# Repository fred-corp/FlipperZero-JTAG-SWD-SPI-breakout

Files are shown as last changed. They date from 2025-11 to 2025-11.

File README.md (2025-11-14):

# Flipper Zero JTAG/SWD/SPI breakout

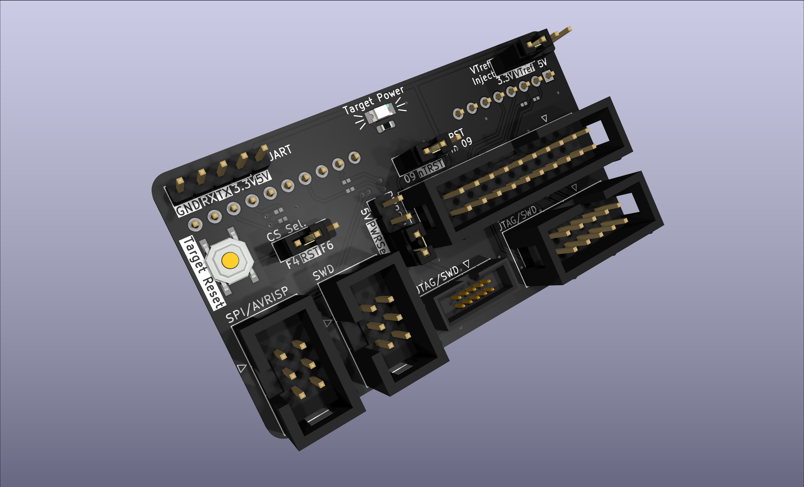
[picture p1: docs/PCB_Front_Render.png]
Flipper Zero JTAG/SWD/SPI breakout board front

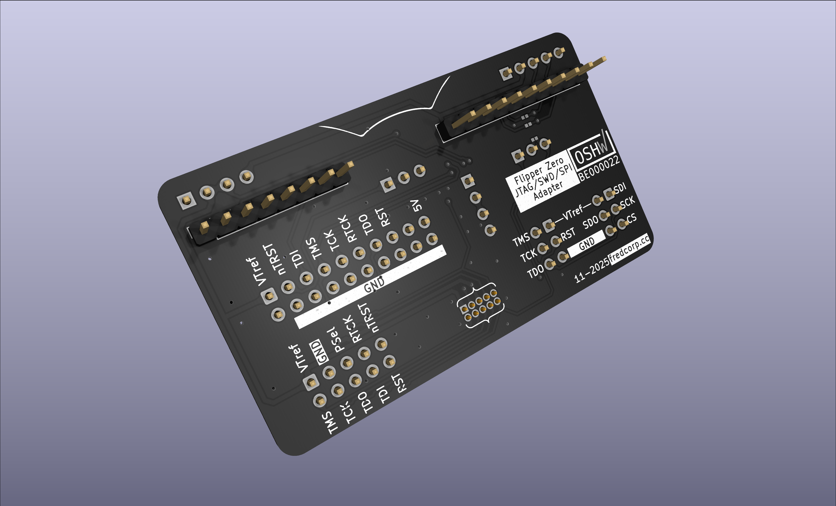
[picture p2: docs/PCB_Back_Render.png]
Flipper Zero JTAG/SWD/SPI breakout board back


A simple breakout board to connect a Flipper Zero to JTAG/SWD/SPI targets.

OSHW ID : [BE000022](https://certification.oshwa.org/be000022.html)

## Table of Contents

- [Features](#features)
  - [Compatible Apps](#compatible-apps)
  - [Pin selection](#pin-selection)
- [Pinouts](#pinouts)
  - [Flipper Zero GPIO header](#flipper-zero-gpio-header)
  - [20 pin JTAG 2x10 0.1" header](#20-pin-jtag-2x10-01-header)
  - [10 pin JTAG/SWD 2x5 0.1" and 0.05" header](#10-pin-jtagswd-2x5-01-and-005-header)
  - [6 pin SWD 2x3 0.1" header](#6-pin-swd-2x3-01-header)
  - [6 pin SPI 2x3 0.1" header](#6-pin-spi-2x3-01-header)
  - [5 pin UART 1x5 0.1" header](#5-pin-uart-1x5-01-header)
- [Usage](#usage)
- [Building Instructions](#building-instructions)
- [Sources](#sources)
- [License & Acknowledgements](#license--acknowledgements)

## Features

Convert the Flipper Zero's GPIO port into standard headers for JTAG, SWD, SPI, and UART connections.

### Compatible Apps

The board should be compatible with any apps that use the Flipper Zero's GPIO port for JTAG/SWD/SPI communication, though the following where the main targets during development for the pin selection and configuration :

- [DAP Link](https://lab.flipper.net/apps/dap_link) (JTAG/SWD & UART)
- [SWD Probe](https://lab.flipper.net/apps/swd_probe) (SWD)
- [SPI Mem Manager](https://lab.flipper.net/apps/spi_mem_manager) (SPI)
- [SPI-Terminal](https://lab.flipper.net/apps/flipper_spi_terminal) (SPI)
- [UART Terminal](https://lab.flipper.net/apps/uart_terminal) (UART)
- [ESP Flasher](https://lab.flipper.net/apps/esp_flasher) (UART)

> **Note** :  
Not all JTAG signals are used by the Flipper Zero apps, but the board can also be used to convert from a 20-pin ARM JTAG connector from another programmer to 10 or 6 pin headers.  
It can also be used as a SWD interface with the Flipper Zero as a target, by bridging the TCK and TMS signals to GPIO 10 and GPIO 12 via their corresponding solder jumpers. This enables programming/debugging the Flipper Zero itself with an external programmer.

### Pin selection

Depending on the app's requirements, some signals can be connected to different GPIO pins of the Flipper Zero using solder jumpers (see assembly instructions/schematics) :

- The TCK signal can be connected to GPIO 2 or GPIO 10
- The TMS signal can be connected to GPIO 3 or GPIO 12
- The UART TX pin can be connected to GPIO 13 or GPIO 15
- The UART RX pin can be connected to GPIO 14 or GPIO 16
- The SPI CS pin can be connected to GPIO 4

Other pins can be configured with jumper shunts :

- The VTref signal can be connected to 3.3V, 5V, or left floating
- The PWRSel signal can be connected to 5V or GND depending on the target's pinout
- The nTRST signal on the 10 pin headers can be connected to nTRST or left floating (NC)
- The SPI CS signal on the 6 pin SPI header can be connected to GPIO 4 or GPIO 6

## Pinouts

> Note : *Italic* pins are configurable with the solder jumpers

### Flipper Zero GPIO header

| Pin | Signals |
|-----|---|
| 1 | 5V |
| 2 | SPI-SDO, *JTAG-TCK* |
| 3 | SPI-SDI, *JTAG-TMS* |
| 4 | *SPI-CS*, JTAG-nRESET |
| 5 | SPI-SCK, JTAG-TDO |
| 6 | *SPI-CS*, JTAG-TDI |
| 7 | NC |
| 8 | GND |
| | |
| 9 | 3.3V |
| 10  | *JTAG-TCK* |
| 11  | GND |
| 12  | *JTAG-TMS* |
| 13  | *UART_TX* |
| 14  | *UART-RX* |
| 15  | *UART-TX* |
| 16  | *UART-RX* |
| 17  | NC |
| 18  | GND |

### 20 pin JTAG 2x10 0.1" header

| Signal | Pin | Pin | Signal |
|---|-----|-----|---|
| VTref | 1 | 2 | NC |
| nTRST | 3 | 4 | GND |
| TDI | 5 | 6 | GND |
| TMS | 7 | 8 | GND |
| TCK | 9 | 10  | GND |
| RTCK | 11  | 12  | GND |
| TDO | 13  | 14  | GND |
| nRESET | 15  | 16  | GND |
| NC | 17  | 18  | GND |
| 5V-Supply | 19  | 20  | GND |

### 10 pin JTAG/SWD 2x5 0.1" and 0.05" header

| Signal | Pin | Pin | Signal |
|---|-----|-----|---|
| VTref | 1 | 2 | TMS |
| GND | 3 | 4 | TCK |
| *PWRSel* | 5 | 6 | TDO |
| RTCK | 7 | 8 | TDI |
| *nTRST/NC* | 9 | 10  | nRESET |

### 6 pin SWD 2x3 0.1" header

| Signal | Pin | Pin | Signal |
|---|-----|-----|---|
| VTref  | 1 | 2 | TMS |
| nRESET | 3 | 4 | TCK |
| GND | 5 | 6 | TDO |

### 6 pin SPI 2x3 0.1" header

| Signal | Pin | Pin | Signal  |
|---|-----|-----|---|
| SDI | 1 | 2 | VTref |
| SCK | 3 | 4 | SDO |
| *CS* | 5 | 6 | GND |

The CS pin can be connected to GPIO 4 or GPIO 6 of the Flipper Zero, depending on the app's requirements.

### 5 pin UART 1x5 0.1" header

| Pin | Signal |
|-----|---|
| 1 | 5V |
| 2 | 3.3V |
| 3 | TX |
| 4 | RX |
| 5 | GND |

## Usage

> TODO : Add usage instructions for some Flipper Zero apps (e.G. DAP Link, SPI mem manager, etc.)

## Building Instructions

> TODO : Add assembly instructions and wiring diagrams from KiCAD sources (awaiting OSHWA certification).

## Sources

- [Flipper Zero Documentation](https://docs.flipperzero.one/)
- [Segger JTAG pinouts](https://www.segger.com/products/debug-probes/j-link/technology/interface-description/)
- [ARM JTAG/SWD pinouts](https://developer.arm.com/documentation/dui0499/d/ARM-DSTREAM-Target-Interface-Connections/)
- [AVR ISP pinouts](https://www.microchip.com/en-us/development-tool/atavrisp2)

## License & Acknowledgements

Made with ❤️, lots of ☕️, and lack of 🛌  
Published under CreativeCommons BY-SA 4.0

  
This work is licensed under a [Creative Commons Attribution-ShareAlike 4.0 International License](http://creativecommons.org/licenses/by-sa/4.0/).

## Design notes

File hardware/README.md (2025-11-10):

# Hardware

This folder contains the KiCAD PCB Project files for the FlipperZero ARM JTAG breakout board.

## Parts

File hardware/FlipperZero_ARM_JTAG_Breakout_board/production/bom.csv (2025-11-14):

Designator | Footprint | Quantity | Value | LCSC Part #
A1a | Flipper_Zero_Straight_8pin | 1 | Flipper_Zero | C42431813
A1b | Flipper_Zero_Straight_10pin | 1 | Flipper_Zero | C42431810
J1 | IDC-Header_2x10_P2.54mm_Vertical | 1 | ARM-JTAG | C429961
J10 | PinHeader_1x03_P2.54mm_Vertical | 1 | nTRST_EN | C42431836
J2 | IDC-Header_2x05_P2.54mm_Vertical | 1 | TC2050-IDC | C429962
J3 | IDC-TH_10P-P1.27-V-M-R2-C5-S1.27 | 1 | 1.27mm | C50878437
J4 | IDC-Header_2x03_P2.54mm_Vertical | 1 | TC2030-IDC | C4749192
J5 | IDC-Header_2x03_P2.54mm_Vertical | 1 | SPI/ISP | C4749192
J6 | PinHeader_1x05_P2.54mm_Vertical | 1 | UART | C42431835
J7 | PinHeader_1x04_P2.54mm_Vertical | 1 | VTrefSel | C42431808
J8 | PinHeader_1x04_P2.54mm_Vertical | 1 | PWRSel | C42431808
J9 | PinHeader_1x03_P2.54mm_Vertical | 1 | RSTSel | C42431836
LED1 | LED1206-R-RD_ORANGE | 1 | XL-3216UOC | C965823
R1 | 0603 | 1 | 150 | C2907103
SW1 | SW-SMD_4P-L5.2-W5.2-P3.70-LS6.4 | 1 | TS1187A16015 | C22375382
 |  | 4 | 2.54mm_shunt | C100114

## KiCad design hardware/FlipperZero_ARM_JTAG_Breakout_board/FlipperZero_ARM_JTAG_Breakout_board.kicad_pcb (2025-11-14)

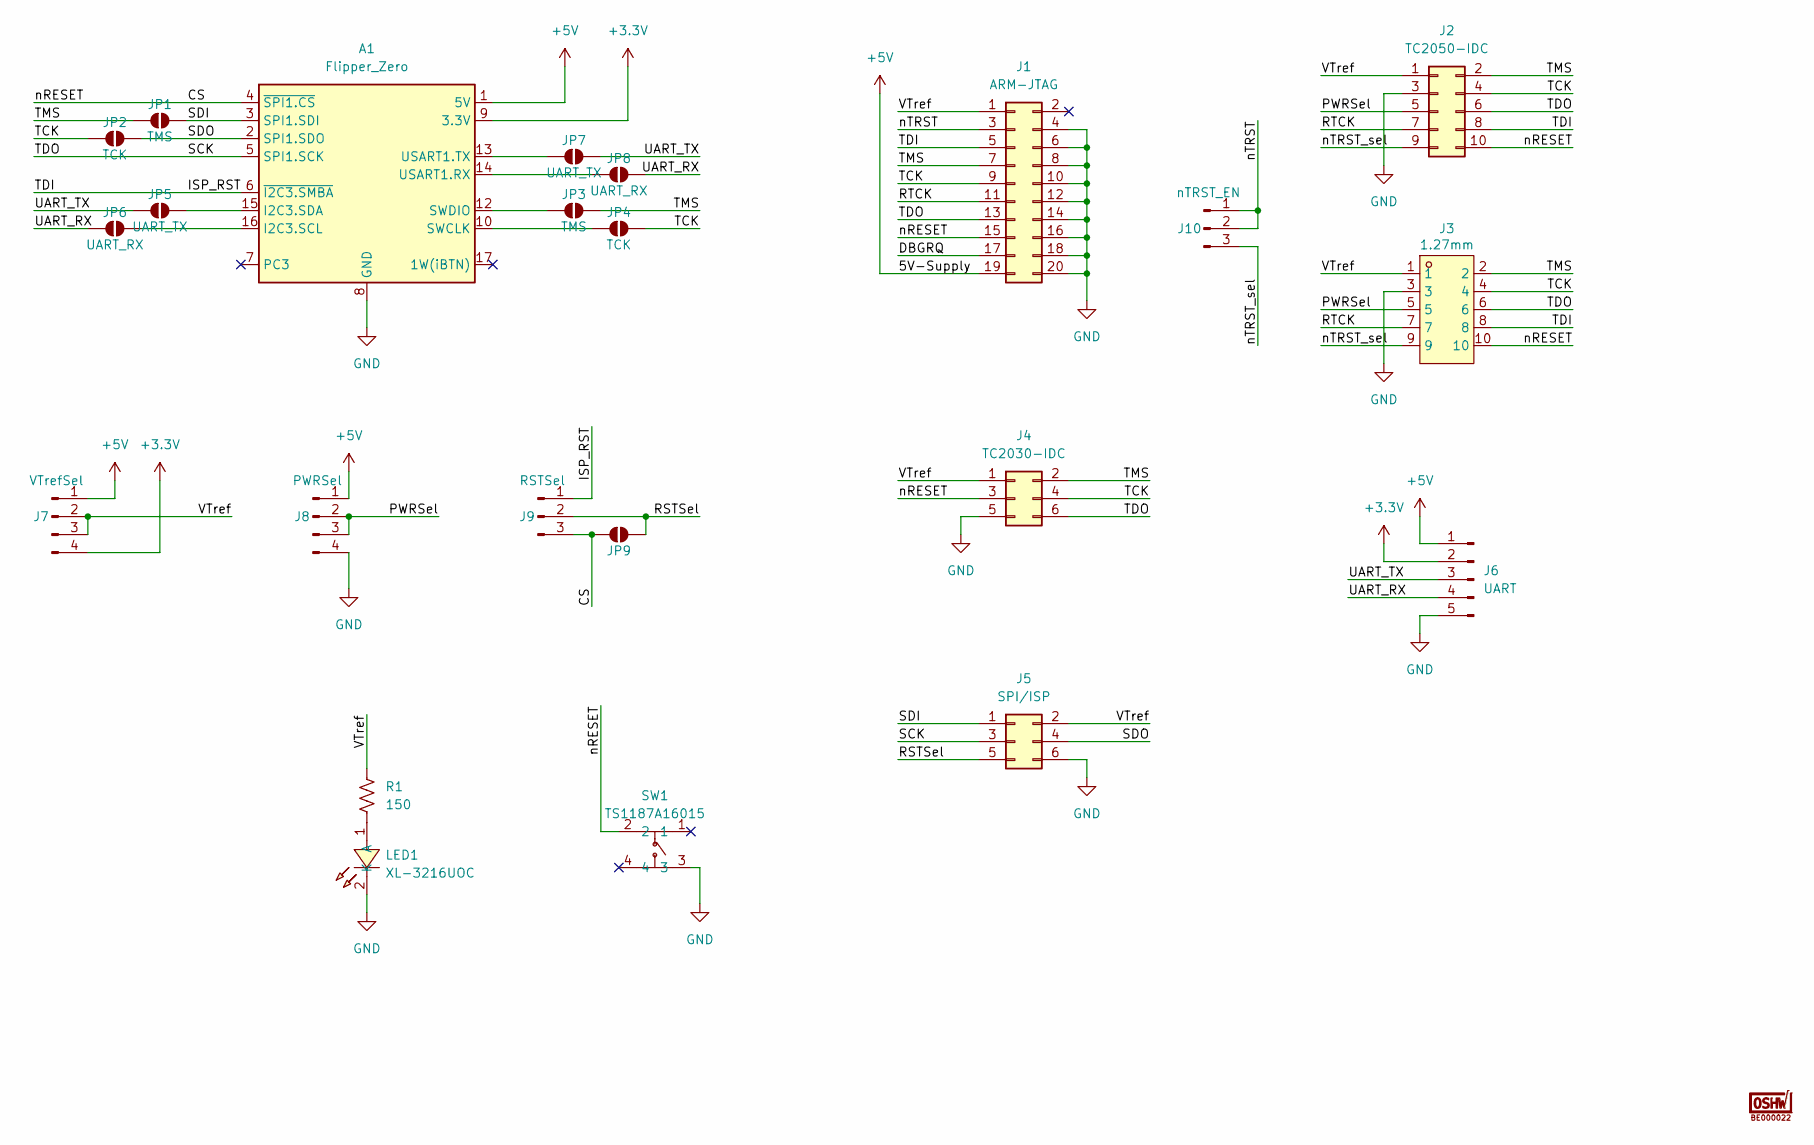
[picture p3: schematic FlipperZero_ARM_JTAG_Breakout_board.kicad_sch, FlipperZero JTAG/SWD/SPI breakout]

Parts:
A1: Flipper_Zero; Flipper_Zero_Straight
J1: ARM-JTAG; IDC-Header_2x10_P2.54mm_Vertical; LCSC Part C429961
J2: TC2050-IDC; IDC-Header_2x05_P2.54mm_Vertical; LCSC Part C429962
J3: 1.27mm; IDC-TH_10P-P1.27-V-M-R2-C5-S1.27; LCSC Part C50878437
J4: TC2030-IDC; IDC-Header_2x03_P2.54mm_Vertical; LCSC Part C4749192
J5: SPI/ISP; IDC-Header_2x03_P2.54mm_Vertical; LCSC Part C4749192
J6: UART; PinHeader_1x05_P2.54mm_Vertical
J7: VTrefSel; PinHeader_1x04_P2.54mm_Vertical
J8: PWRSel; PinHeader_1x04_P2.54mm_Vertical
J9: RSTSel; PinHeader_1x03_P2.54mm_Vertical
J10: nTRST_EN; PinHeader_1x03_P2.54mm_Vertical
JP1, JP3, JP9: TMS; JUMPER_SMD_1x2_tiny
JP2, JP4: TCK; JUMPER_SMD_1x2_tiny
JP5, JP7: UART_TX; JUMPER_SMD_1x2_tiny
JP6, JP8: UART_RX; JUMPER_SMD_1x2_tiny
LED1: XL-3216UOC; LED1206-R-RD_ORANGE; LCSC Part C965823
LOGO1: BE000022; OSHW-Certification-Mark-Stacked_8x7mm_SilkMask
R1: 150; R_0603_1608Metric_Pad0.98x0.95mm_HandSolder; LCSC Part C2907103
SW1: TS1187A16015; SW-SMD_4P-L5.2-W5.2-P3.70-LS6.4; LCSC Part C22375382

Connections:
+3.3V: A1.9 (3.3V), J6.2, J7.4
+5V: A1.1 (5V), J1.19, J6.1, J7.1, J8.1
/CS: A1.4 (~SPI1.CS), J1.15, J2.10, J3.10, J4.3, J9.3, JP9.1 (A), SW1.2
/DBGRQ: J1.17
/ISP_RST: A1.6 (~I2C3.SMBA), J1.5, J2.8, J3.8, J9.1
/PWRSel: J2.5, J3.5, J8.2, J8.3
/RSTSel: J5.5, J9.2, JP9.2 (B)
/RTCK: J1.11, J2.7, J3.7
/SCK: A1.5 (SPI1.SCK), J1.13, J2.6, J3.6, J4.6, J5.3
/SDI: A1.3 (SPI1.SDI), J5.1, JP1.1 (A)
/SDO: A1.2 (SPI1.SDO), J5.4, JP2.1 (A)
/TCK: J1.9, J2.4, J3.4, J4.4, JP2.2 (B), JP4.2 (B)
/TMS: J1.7, J2.2, J3.2, J4.2, JP1.2 (B), JP3.2 (B)
/UART_RX: J6.4, JP6.2 (B), JP8.2 (B)
/UART_TX: J6.3, JP5.2 (B), JP7.2 (B)
/VTref: J1.1, J2.1, J3.1, J4.1, J5.2, J7.2, J7.3, R1.1
/nTRST: J1.3, J10.1, J10.2
/nTRST_sel: J2.9, J3.9, J10.3
GND: A1.8 (GND), A1.11 (GND), A1.18 (GND), J1.4, J1.6, J1.8, J1.10, J1.12, J1.14, J1.16, J1.18, J1.20, J2.3, J3.3, J4.5, J5.6, J6.5, J8.4, LED1.2 (K), SW1.3
unnamed: A1.16 (I2C3.SCL), JP6.1 (A)
unnamed: A1.15 (I2C3.SDA), JP5.1 (A)
unnamed: A1.10 (SWCLK), JP4.1 (A)
unnamed: A1.12 (SWDIO), JP3.1 (A)
unnamed: A1.14 (USART1.RX), JP8.1 (A)
unnamed: A1.13 (USART1.TX), JP7.1 (A)
unnamed: LED1.1 (A), R1.2

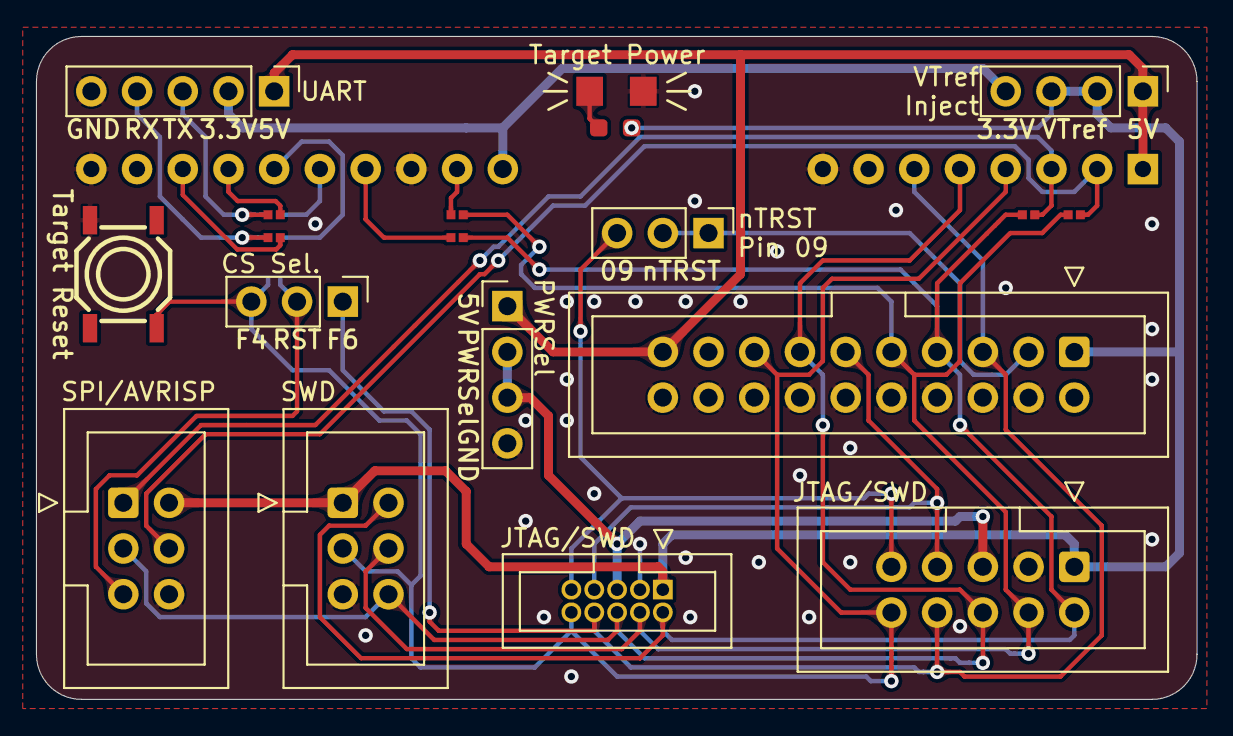
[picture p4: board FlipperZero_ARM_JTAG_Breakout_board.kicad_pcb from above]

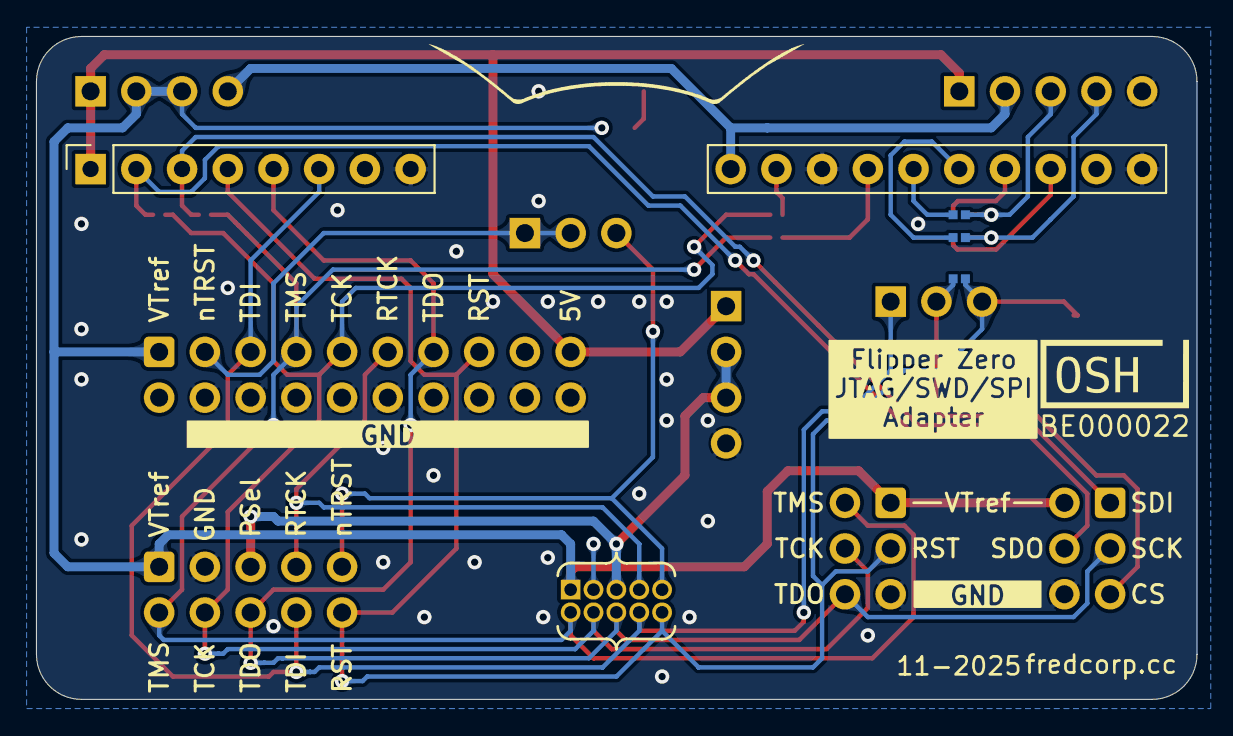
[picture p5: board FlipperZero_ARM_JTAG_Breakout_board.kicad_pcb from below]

Board: 2 copper layers, 64.5 x 36.8 mm, 24 parts (5 on the bottom side), 25 nets.

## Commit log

2025-11-10 added KiCAD sources
    [FlipperZero_ARM_JTAG_Breakout_board-rounded.kicad_pcb, FlipperZero_ARM_JTAG_Breakout_board.kicad_pcb, FlipperZero_ARM_JTAG_Breakout_board.kicad_sch]
2025-11-10 added OSHW footprint template
    [FlipperZero_ARM_JTAG_Breakout_board.kicad_pcb, FlipperZero_ARM_JTAG_Breakout_board.kicad_sch]
2025-11-10 updated signal names for up-to-date terminology
    [FlipperZero_ARM_JTAG_Breakout_board.kicad_pcb, FlipperZero_ARM_JTAG_Breakout_board.kicad_sch]
2025-11-10 updated footprint & ran DRU check
    [FlipperZero_ARM_JTAG_Breakout_board.kicad_pcb, FlipperZero_ARM_JTAG_Breakout_board.kicad_sch]
2025-11-11 added compatible apps, flipper GPIO pinout, UART pinout
2025-11-11 added jumpers on 3D models, fixed silkscreen names
    [FlipperZero_ARM_JTAG_Breakout_board.kicad_pcb]
2025-11-11 added PCB render image in README
2025-11-11 added PCB front and back render images to README
2025-11-11 Fixed typo in silkscreen
    [FlipperZero_ARM_JTAG_Breakout_board.kicad_pcb]
2025-11-14 added OSHWA Certification ID
    [FlipperZero_ARM_JTAG_Breakout_board.kicad_pcb, FlipperZero_ARM_JTAG_Breakout_board.kicad_sch]
2025-11-14 removed rounded tracks version
    [FlipperZero_ARM_JTAG_Breakout_board-rounded.kicad_pcb]
2025-11-14 added fabrication files
    [bom.csv, designators.csv, positions.csv]
2025-11-14 final save
    [FlipperZero_ARM_JTAG_Breakout_board.kicad_pcb]
